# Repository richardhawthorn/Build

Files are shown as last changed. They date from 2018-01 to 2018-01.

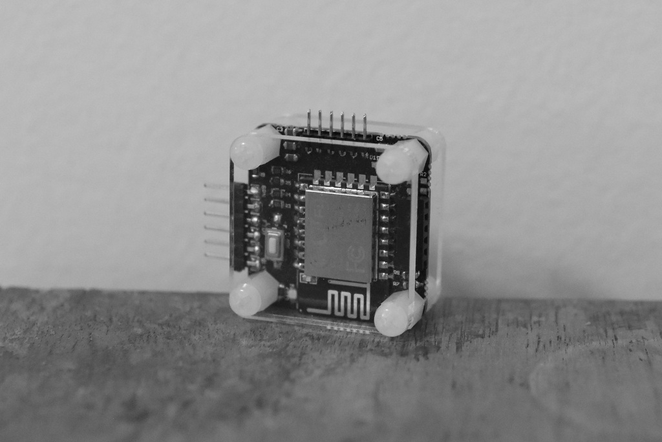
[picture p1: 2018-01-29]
Boards/Wifi Base/images/DSC_7675.JPG

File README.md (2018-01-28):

### Description

'Build' is an interchangeable set of input/output boards that let you create a complex system of sensors, buttons, actuators, transmitters and screens. Build starts with a wifi base and adds 13 different individually addressed i/o boards.  All boards clip together using a standard 6 pin header, so expanding the system quick and easy. 

This work is licensed under a Creative Commons Attribution-ShareAlike 4.0 International License.

<br />
Designed by <a xmlns:cc="http://creativecommons.org/ns#" href="http://www.richardhawthorn.com" property="cc:attributionName" rel="cc:attributionURL" target="_blank">Richard Hawthorn</a><br />
<a rel="license" href="http://creativecommons.org/licenses/by-sa/4.0/" target="_blank">View License</a>

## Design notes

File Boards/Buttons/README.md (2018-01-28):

### Description

Capacative button board for use in build system

### Features

- 4 capacative buttons on front plate
- QT1070 capacative chip
- ATtiny44 processor
- DIL switch for 8 board addresses
- i2c communication with base
- 3.3v operation
- Surface mount

### License

This work is licensed under a Creative Commons Attribution-ShareAlike 4.0 International License.

<br />
Designed by <a xmlns:cc="http://creativecommons.org/ns#" href="http://www.richardhawthorn.com" property="cc:attributionName" rel="cc:attributionURL" target="_blank">Richard Hawthorn</a><br />
<a rel="license" href="http://creativecommons.org/licenses/by-sa/4.0/" target="_blank">View License</a>

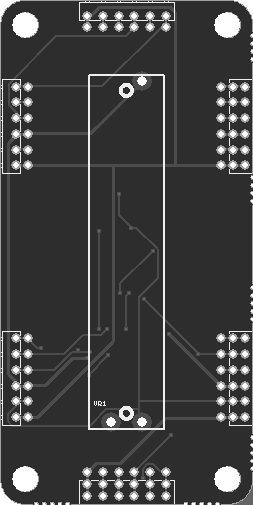
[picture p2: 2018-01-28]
Boards/Slider/images/pcb_front.png

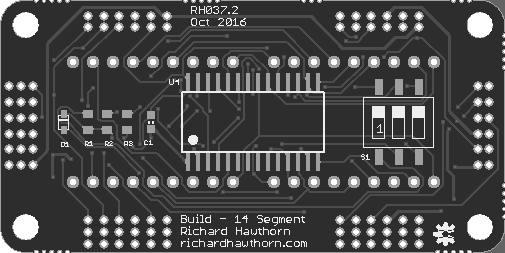
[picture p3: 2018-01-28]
Boards/14 Segment/images/pcb_back.png

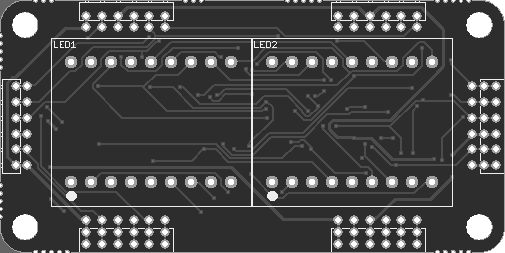
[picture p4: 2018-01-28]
Boards/14 Segment/images/pcb_front.png

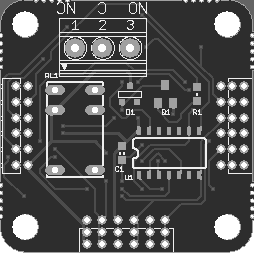
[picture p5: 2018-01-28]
Boards/Relay/images/pcb_front.png

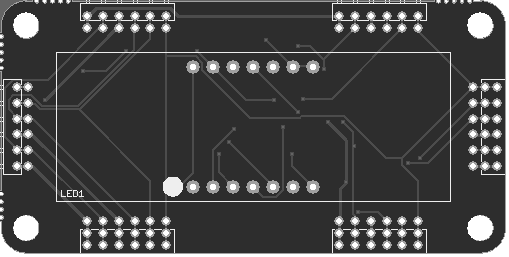
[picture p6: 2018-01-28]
Boards/7 Segment/images/pcb_front.png

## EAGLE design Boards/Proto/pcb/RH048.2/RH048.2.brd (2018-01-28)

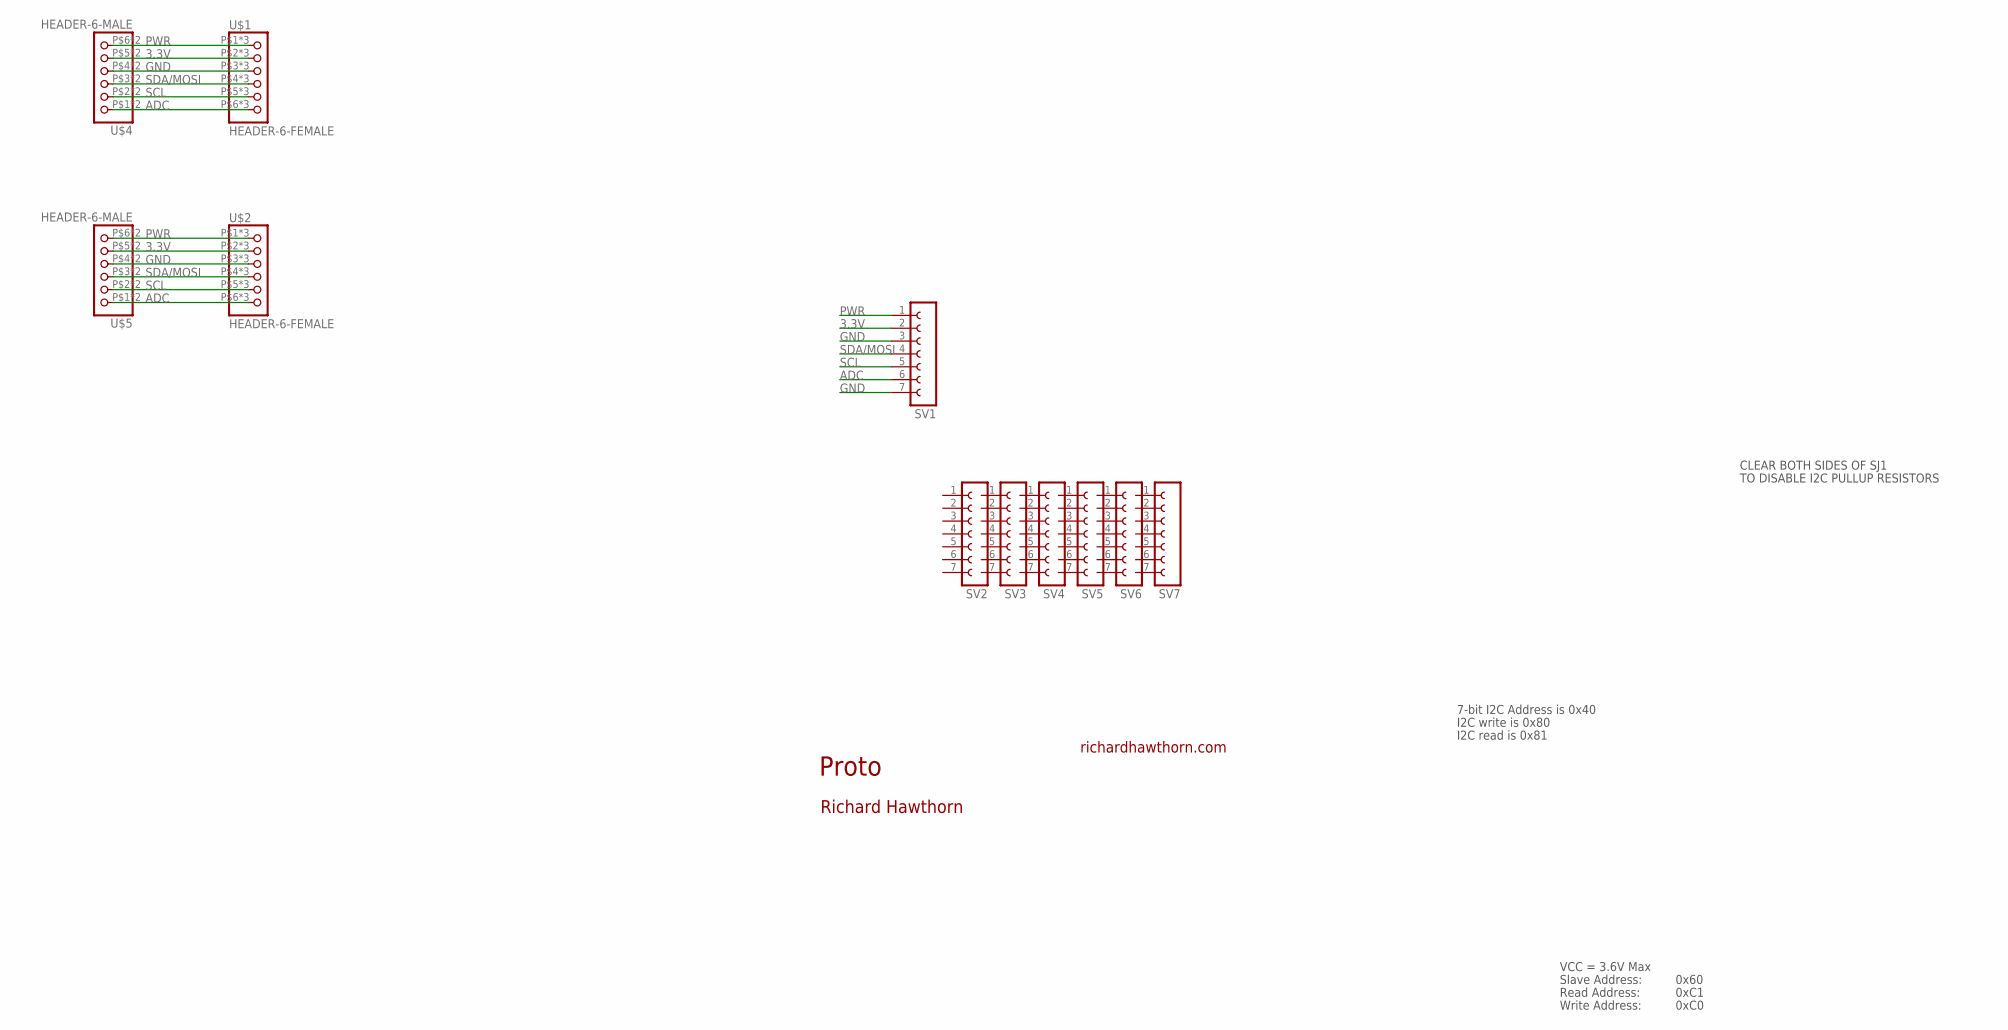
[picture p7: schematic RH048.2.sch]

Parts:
SV1, SV2, SV3, SV4, SV5, SV6, SV7: FE07-1; FE07
U$1, U$2: HEADER-6-FEMALE; 2MMHEADER6
U$4, U$5: HEADER-6-MALE; 2MMHEADERPIN6

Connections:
3.3V: SV1.2, U$1.P$2 (2), U$1.P$10 (2), U$1.P$18 (2), U$2.P$2 (2), U$2.P$10 (2), U$2.P$18 (2), U$4.P$5 (5), U$4.P$13 (5), U$5.P$5 (5), U$5.P$13 (5)
ADC: SV1.6, U$1.P$6 (6), U$1.P$14 (6), U$1.P$22 (6), U$2.P$6 (6), U$2.P$14 (6), U$2.P$22 (6), U$4.P$1 (1), U$4.P$9 (1), U$5.P$1 (1), U$5.P$9 (1)
GND: SV1.3, SV1.7, U$1.P$3 (3), U$1.P$11 (3), U$1.P$19 (3), U$2.P$3 (3), U$2.P$11 (3), U$2.P$19 (3), U$4.P$4 (4), U$4.P$12 (4), U$5.P$4 (4), U$5.P$12 (4)
PWR: SV1.1, U$1.P$1 (1), U$1.P$9 (1), U$1.P$17 (1), U$2.P$1 (1), U$2.P$9 (1), U$2.P$17 (1), U$4.P$6 (6), U$4.P$14 (6), U$5.P$6 (6), U$5.P$14 (6)
SCL: SV1.5, U$1.P$5 (5), U$1.P$13 (5), U$1.P$21 (5), U$2.P$5 (5), U$2.P$13 (5), U$2.P$21 (5), U$4.P$2 (2), U$4.P$10 (2), U$5.P$2 (2), U$5.P$10 (2)
SDA/MOSI: SV1.4, U$1.P$4 (4), U$1.P$12 (4), U$1.P$20 (4), U$2.P$4 (4), U$2.P$12 (4), U$2.P$20 (4), U$4.P$3 (3), U$4.P$11 (3), U$5.P$3 (3), U$5.P$11 (3)

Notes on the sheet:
Proto
richardhawthorn.com
Richard Hawthorn
CLEAR BOTH SIDES OF SJ1
TO DISABLE I2C PULLUP RESISTORS
7-bit I2C Address is 0x40
I2C write is 0x80
I2C read is 0x81
VCC = 3.6V Max
Read Address:
Write Address:
Slave Address:
0x60
0xC1
0xC0

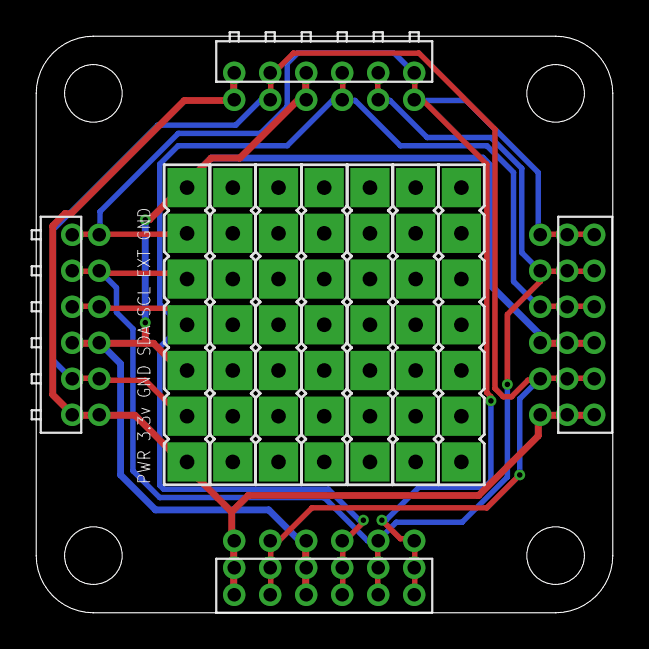
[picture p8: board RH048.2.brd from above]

Board: 2 copper layers, 32.0 x 32.0 mm, 12 parts (1 on the bottom side), 6 nets.

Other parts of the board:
U$3: OSHW-LOGO-S

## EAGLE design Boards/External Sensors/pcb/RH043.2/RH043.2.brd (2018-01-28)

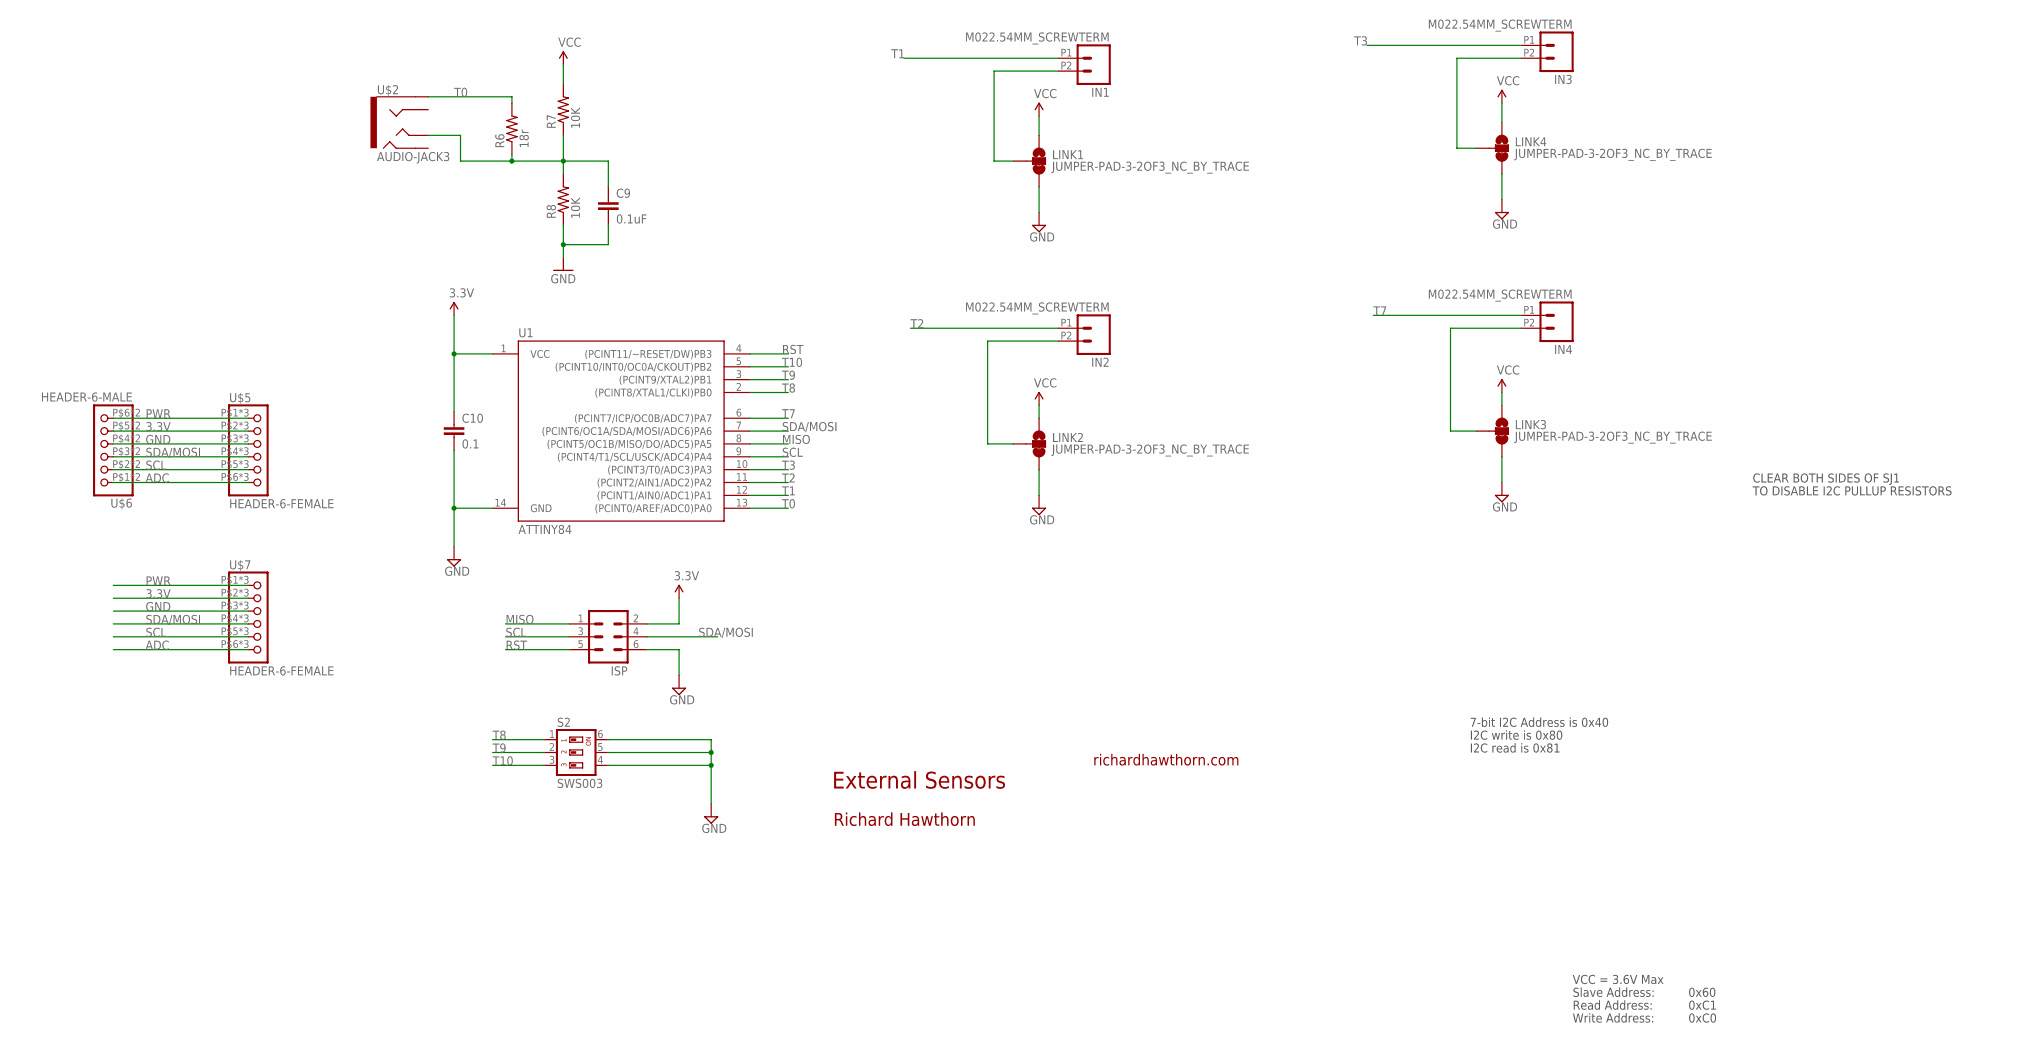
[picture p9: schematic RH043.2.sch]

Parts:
C9: 0.1uF; 0603-CAP
C10: 0.1; 0603-CAP
IN1, IN2, IN3, IN4: M022.54MM_SCREWTERM; 1X02_2.54_SCREWTERM
ISP: MA03-2
LINK1, LINK2, LINK3, LINK4: JUMPER-PAD-3-2OF3_NC_BY_TRACE; PAD-JUMPER-3-2OF3_NC_BY_TRACE_YES_SILK_FULL_BOX
R6: 18r; 0603-RES
R7, R8: 10K; 0603-RES
S2: SWS003; SMS-003
U1: ATTINY84; SO14
U$2: AUDIO-JACK3; AUDIO-JACK-TRRS-SMD
U$5, U$7: HEADER-6-FEMALE; 2MMHEADER6
U$6: HEADER-6-MALE; 2MMHEADERPIN6

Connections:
3.3V: C10.1, ISP.2, LINK1.1, LINK2.1, LINK3.1, LINK4.1, R7.2, U1.1 (VCC), U$5.P$2 (2), U$5.P$10 (2), U$5.P$18 (2), U$6.P$5 (5), U$6.P$13 (5), U$7.P$2 (2), U$7.P$10 (2), U$7.P$18 (2)
ADC: U$5.P$6 (6), U$5.P$14 (6), U$5.P$22 (6), U$6.P$1 (1), U$6.P$9 (1), U$7.P$6 (6), U$7.P$14 (6), U$7.P$22 (6)
GND: C9.2, C10.2, ISP.6, LINK1.3, LINK2.3, LINK3.3, LINK4.3, R8.1, S2.4, S2.5, S2.6, U1.14 (GND), U$5.P$3 (3), U$5.P$11 (3), U$5.P$19 (3), U$6.P$4 (4), U$6.P$12 (4), U$7.P$3 (3), U$7.P$11 (3), U$7.P$19 (3)
MISO: ISP.1, U1.8 ((PCINT5/OC1B/MISO/DO/ADC5)PA5)
unnamed: IN3.P2 (2), LINK4.2
unnamed: IN4.P2 (2), LINK3.2
unnamed: IN1.P2 (2), LINK1.2
unnamed: IN2.P2 (2), LINK2.2
PWR: U$5.P$1 (1), U$5.P$9 (1), U$5.P$17 (1), U$6.P$6 (6), U$6.P$14 (6), U$7.P$1 (1), U$7.P$9 (1), U$7.P$17 (1)
R6: C9.1, R6.1, R7.1, R8.2, U$2.TIP
RST: ISP.5, U1.4 ((PCINT11/~RESET/DW)PB3)
SCL: ISP.3, U1.9 ((PCINT4/T1/SCL/USCK/ADC4)PA4), U$5.P$5 (5), U$5.P$13 (5), U$5.P$21 (5), U$6.P$2 (2), U$6.P$10 (2), U$7.P$5 (5), U$7.P$13 (5), U$7.P$21 (5)
SDA/MOSI: ISP.4, U1.7 ((PCINT6/OC1A/SDA/MOSI/ADC6)PA6), U$5.P$4 (4), U$5.P$12 (4), U$5.P$20 (4), U$6.P$3 (3), U$6.P$11 (3), U$7.P$4 (4), U$7.P$12 (4), U$7.P$20 (4)
T0: R6.2, U1.13 ((PCINT0/AREF/ADC0)PA0), U$2.EARTH
T1: IN1.P1 (1), U1.12 ((PCINT1/AIN0/ADC1)PA1)
T2: IN2.P1 (1), U1.11 ((PCINT2/AIN1/ADC2)PA2)
T3: IN3.P1 (1), U1.10 ((PCINT3/T0/ADC3)PA3)
T7: IN4.P1 (1), U1.6 ((PCINT7/ICP/OC0B/ADC7)PA7)
T8: S2.1, U1.2 ((PCINT8/XTAL1/CLKI)PB0)
T9: S2.2, U1.3 ((PCINT9/XTAL2)PB1)
T10: S2.3, U1.5 ((PCINT10/INT0/OC0A/CKOUT)PB2)

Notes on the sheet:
External Sensors
richardhawthorn.com
Richard Hawthorn
CLEAR BOTH SIDES OF SJ1
TO DISABLE I2C PULLUP RESISTORS
7-bit I2C Address is 0x40
I2C write is 0x80
I2C read is 0x81
VCC = 3.6V Max
Read Address:
Write Address:
Slave Address:
0x60
0xC1
0xC0

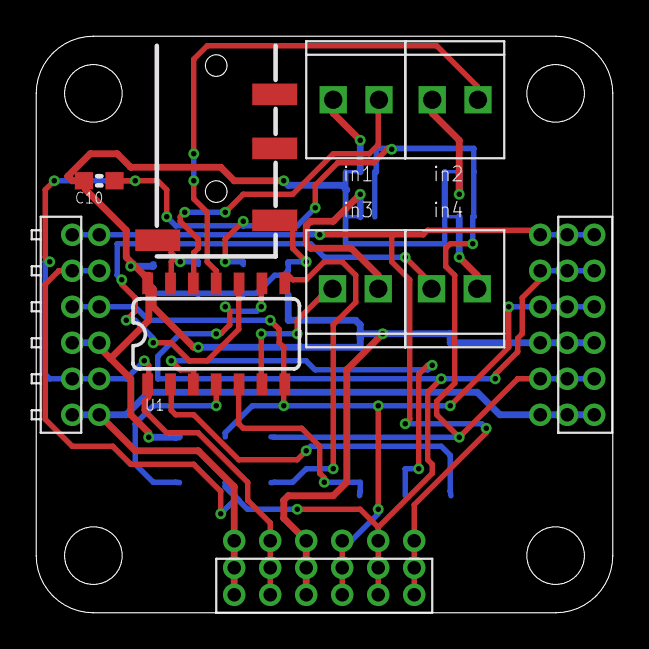
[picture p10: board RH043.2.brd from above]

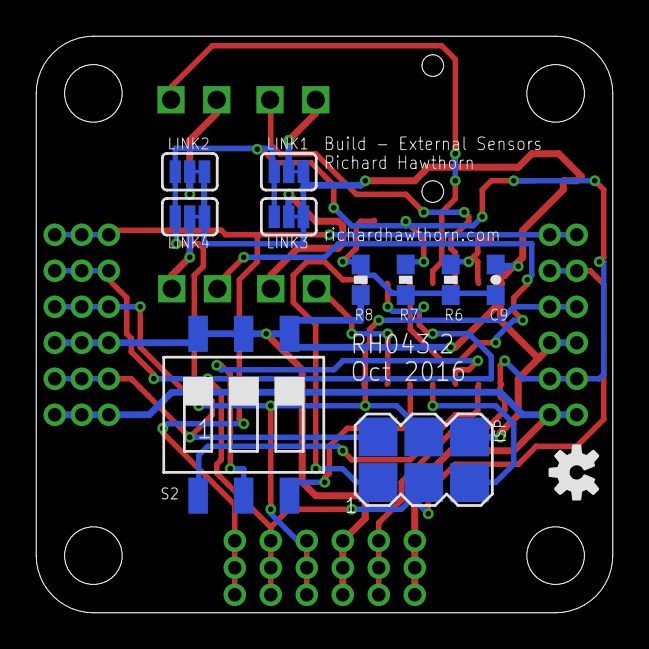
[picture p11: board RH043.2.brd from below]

Board: 2 copper layers, 32.0 x 32.0 mm, 21 parts (11 on the bottom side), 21 nets.

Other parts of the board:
U$3: OSHW-LOGO-S

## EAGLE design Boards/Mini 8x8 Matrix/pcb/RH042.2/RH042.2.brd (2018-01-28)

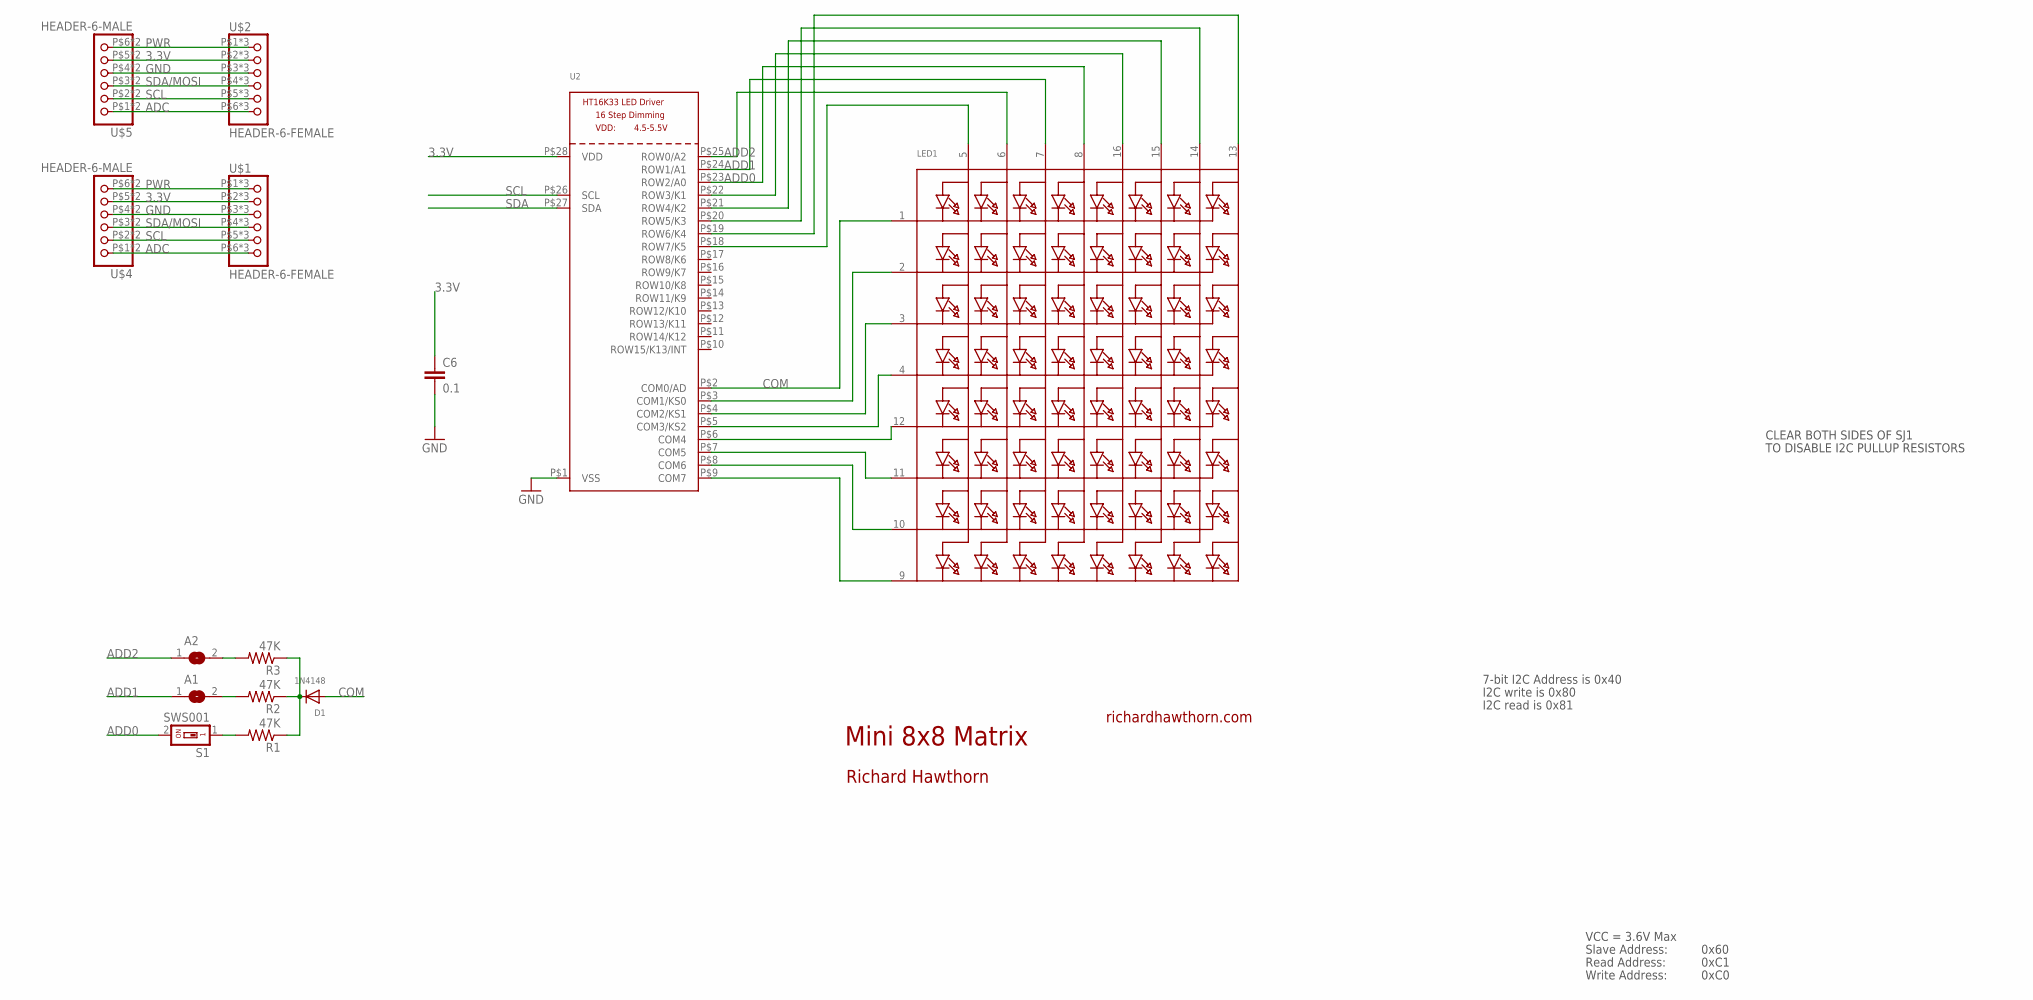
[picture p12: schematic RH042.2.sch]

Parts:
A1, A2: SJ
C6: 0.1; 0603-CAP
D1: 1N4148; SOD-323F
LED1: SEGMENT_8X8_ROWCATHODE; SEGMENT_BL-M07C881UR
R1, R2, R3: 47K; R0805
S1: SWS001; SMS-001
U2: HT16K33_SOP28; SOP28_300MIL
U$1, U$2: HEADER-6-FEMALE; 2MMHEADER6
U$4, U$5: HEADER-6-MALE; 2MMHEADERPIN6

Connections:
3.3V: C6.1, U2.P$28 (VDD), U$1.P$2 (2), U$1.P$10 (2), U$1.P$18 (2), U$2.P$2 (2), U$2.P$10 (2), U$2.P$18 (2), U$4.P$5 (5), U$4.P$13 (5), U$5.P$5 (5), U$5.P$13 (5)
ADC: U$1.P$6 (6), U$1.P$14 (6), U$1.P$22 (6), U$2.P$6 (6), U$2.P$14 (6), U$2.P$22 (6), U$4.P$1 (1), U$4.P$9 (1), U$5.P$1 (1), U$5.P$9 (1)
ADD0: LED1.8 (A4), S1.2, U2.P$23 (ROW2/A0)
ADD1: A1.1, LED1.7 (A3), U2.P$24 (ROW1/A1)
ADD2: A2.1, LED1.6 (A2), U2.P$25 (ROW0/A2)
COM: D1.A, LED1.1 (K1), U2.P$2 (COM0/AD)
GND: C6.2, U2.P$1 (VSS), U$1.P$3 (3), U$1.P$11 (3), U$1.P$19 (3), U$2.P$3 (3), U$2.P$11 (3), U$2.P$19 (3), U$4.P$4 (4), U$4.P$12 (4), U$5.P$4 (4), U$5.P$12 (4)
unnamed: LED1.9 (K8), U2.P$9 (COM7)
unnamed: A2.2, R3.2
unnamed: LED1.10 (K7), U2.P$8 (COM6)
unnamed: LED1.11 (K6), U2.P$7 (COM5)
unnamed: D1.C, R1.1, R2.1, R3.1
unnamed: R1.2, S1.1
unnamed: A1.2, R2.2
unnamed: LED1.12 (K5), U2.P$6 (COM4)
unnamed: LED1.4 (K4), U2.P$5 (COM3/KS2)
unnamed: LED1.3 (K3), U2.P$4 (COM2/KS1)
unnamed: LED1.2 (K2), U2.P$3 (COM1/KS0)
unnamed: LED1.16 (A5), U2.P$22 (ROW3/K1)
unnamed: LED1.15 (A6), U2.P$21 (ROW4/K2)
unnamed: LED1.5 (A1), U2.P$18 (ROW7/K5)
PWR: U$1.P$1 (1), U$1.P$9 (1), U$1.P$17 (1), U$2.P$1 (1), U$2.P$9 (1), U$2.P$17 (1), U$4.P$6 (6), U$4.P$14 (6), U$5.P$6 (6), U$5.P$14 (6)
SCL: U2.P$26 (SCL), U$1.P$5 (5), U$1.P$13 (5), U$1.P$21 (5), U$2.P$5 (5), U$2.P$13 (5), U$2.P$21 (5), U$4.P$2 (2), U$4.P$10 (2), U$5.P$2 (2), U$5.P$10 (2)
SDA: U2.P$27 (SDA)
SDA/MOSI: U$1.P$4 (4), U$1.P$12 (4), U$1.P$20 (4), U$2.P$4 (4), U$2.P$12 (4), U$2.P$20 (4), U$4.P$3 (3), U$4.P$11 (3), U$5.P$3 (3), U$5.P$11 (3)
SEG_F: LED1.14 (A7), U2.P$20 (ROW5/K3)
SEG_G: LED1.13 (A8), U2.P$19 (ROW6/K4)

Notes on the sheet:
Mini 8x8 Matrix
richardhawthorn.com
Richard Hawthorn
CLEAR BOTH SIDES OF SJ1
TO DISABLE I2C PULLUP RESISTORS
7-bit I2C Address is 0x40
I2C write is 0x80
I2C read is 0x81
VCC = 3.6V Max
Read Address:
Write Address:
Slave Address:
0x60
0xC1
0xC0

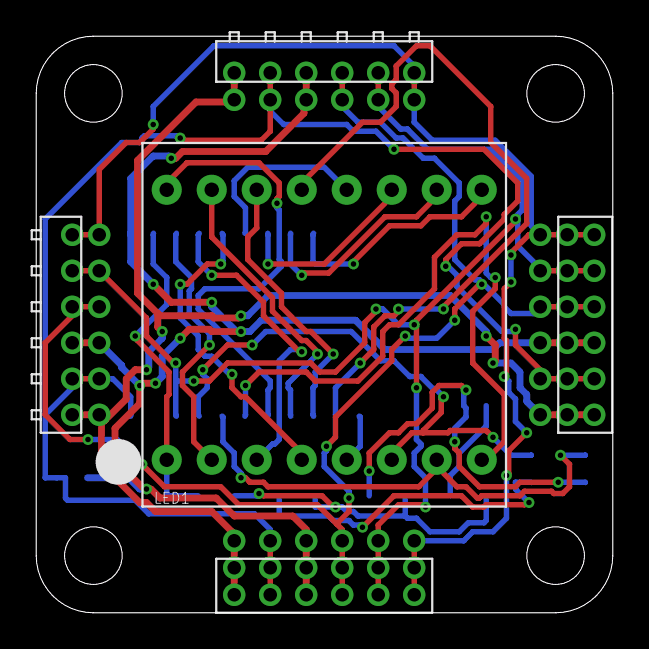
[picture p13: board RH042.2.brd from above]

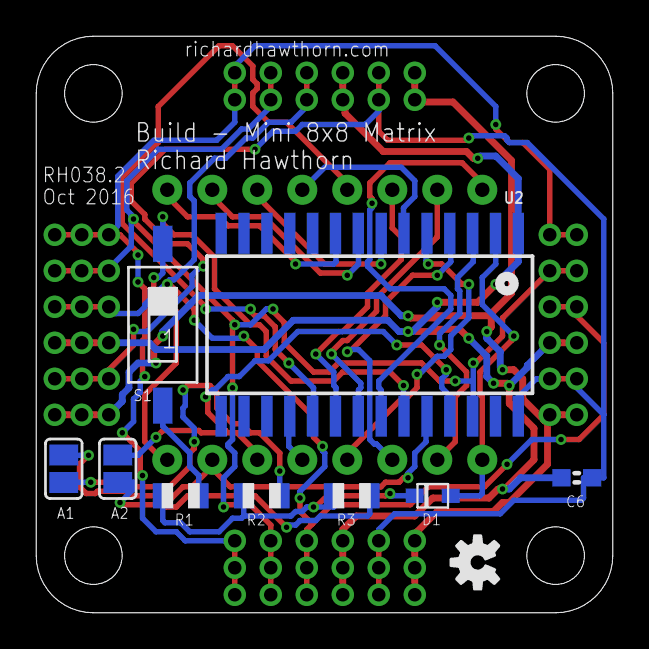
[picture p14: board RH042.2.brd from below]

Board: 2 copper layers, 32.0 x 32.0 mm, 15 parts (10 on the bottom side), 26 nets.

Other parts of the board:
U$3: OSHW-LOGO-S

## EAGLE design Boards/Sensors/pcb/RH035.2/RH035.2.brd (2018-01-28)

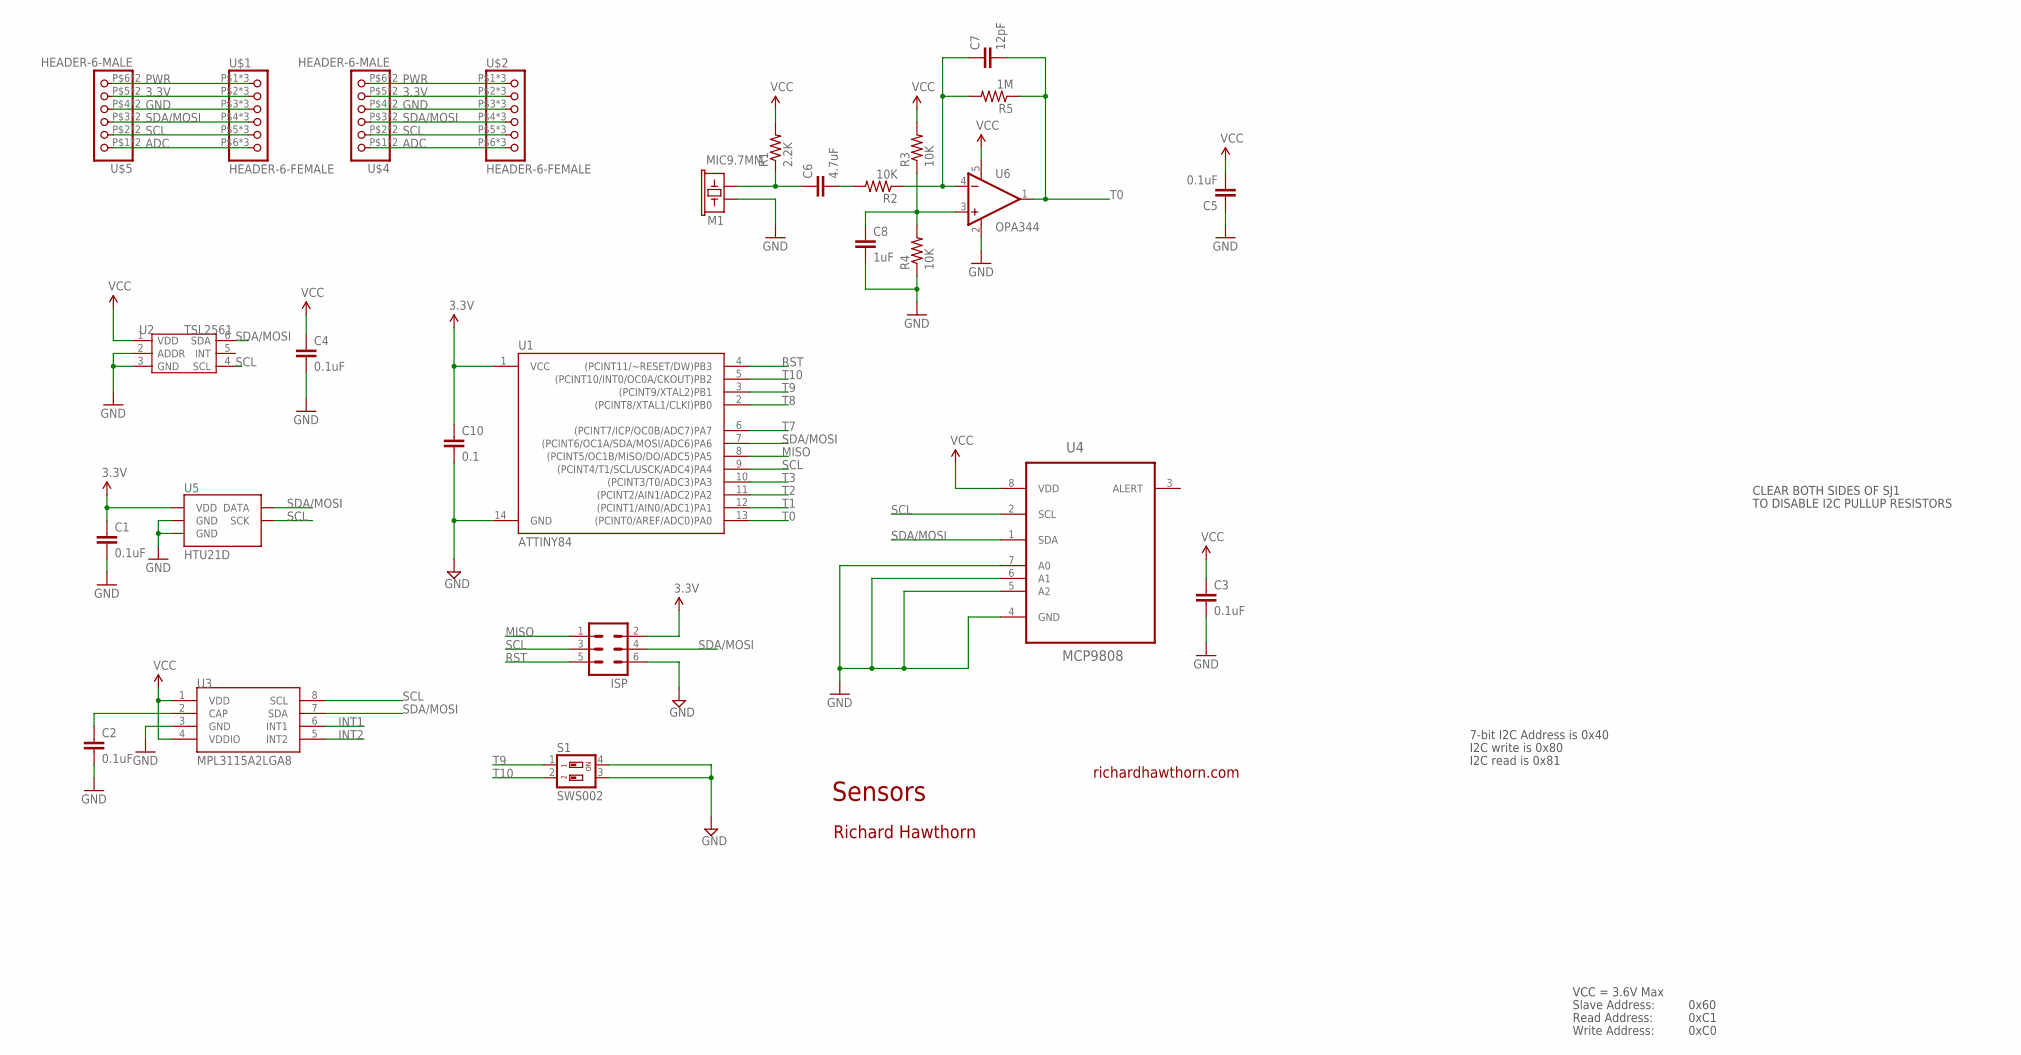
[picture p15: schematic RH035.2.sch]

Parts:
C1, C2, C5: 0.1uF; 0805
C3, C4: 0.1uF; 0603-CAP
C6: 4.7uF; 0805
C7: 12pF; 0805
C8: 1uF; 0805
C10: 0.1; 0603-CAP
ISP: MA03-2
M1: MIC9.7MM; MIC-9.7MM
R1: 2.2K; 0805
R2, R3, R4: 10K; 0805
R5: 1M; 0805
S1: SWS002; SMS-002
U1: ATTINY84; SO14
U2: TSL2561; TMB-6
U3: MPL3115A2LGA8; LGA8
U4: MCP9808; SOP65P490X110-8N
U5: HTU21D
U6: OPA344; SOT23-5
U$1, U$2: HEADER-6-FEMALE; 2MMHEADER6
U$4, U$5: HEADER-6-MALE; 2MMHEADERPIN6

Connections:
3.3V: C1.1, C3.1, C4.1, C5.2, C10.1, ISP.2, R1.2, R3.2, U1.1 (VCC), U2.1 (VDD), U3.1 (VDD), U3.4 (VDDIO), U4.8 (VDD), U5.VDD, U6.5 (V+), U$1.P$2 (2), U$1.P$10 (2), U$1.P$18 (2), U$2.P$2 (2), U$2.P$10 (2), U$2.P$18 (2), U$4.P$5 (5), U$4.P$13 (5), U$5.P$5 (5), U$5.P$13 (5)
ADC: U$1.P$6 (6), U$1.P$14 (6), U$1.P$22 (6), U$2.P$6 (6), U$2.P$14 (6), U$2.P$22 (6), U$4.P$1 (1), U$4.P$9 (1), U$5.P$1 (1), U$5.P$9 (1)
GND: C1.2, C2.2, C3.2, C4.2, C5.1, C8.2, C10.2, ISP.6, M1.2, R4.1, S1.3, S1.4, U1.14 (GND), U2.2 (ADDR), U2.3 (GND), U3.3 (GND), U4.4 (GND), U4.5 (A2), U4.6 (A1), U4.7 (A0), U5.7 (GND), U5.GND, U6.2 (V-), U$1.P$3 (3), U$1.P$11 (3), U$1.P$19 (3), U$2.P$3 (3), U$2.P$11 (3), U$2.P$19 (3), U$4.P$4 (4), U$4.P$12 (4), U$5.P$4 (4), U$5.P$12 (4)
INT1: U3.6 (INT1)
INT2: U3.5 (INT2)
MISO: ISP.1, U1.8 ((PCINT5/OC1B/MISO/DO/ADC5)PA5)
unnamed: C6.1, M1.1, R1.1
unnamed: C7.1, R2.1, R5.2, U6.4 (-IN)
unnamed: C6.2, R2.2
unnamed: C8.1, R3.1, R4.2, U6.3 (+IN)
unnamed: C2.1, U3.2 (CAP)
PWR: U$1.P$1 (1), U$1.P$9 (1), U$1.P$17 (1), U$2.P$1 (1), U$2.P$9 (1), U$2.P$17 (1), U$4.P$6 (6), U$4.P$14 (6), U$5.P$6 (6), U$5.P$14 (6)
RST: ISP.5, U1.4 ((PCINT11/~RESET/DW)PB3)
SCL: ISP.3, U1.9 ((PCINT4/T1/SCL/USCK/ADC4)PA4), U2.4 (SCL), U3.8 (SCL), U4.2 (SCL), U5.SCK, U$1.P$5 (5), U$1.P$13 (5), U$1.P$21 (5), U$2.P$5 (5), U$2.P$13 (5), U$2.P$21 (5), U$4.P$2 (2), U$4.P$10 (2), U$5.P$2 (2), U$5.P$10 (2)
SDA/MOSI: ISP.4, U1.7 ((PCINT6/OC1A/SDA/MOSI/ADC6)PA6), U2.6 (SDA), U3.7 (SDA), U4.1 (SDA), U5.DATA, U$1.P$4 (4), U$1.P$12 (4), U$1.P$20 (4), U$2.P$4 (4), U$2.P$12 (4), U$2.P$20 (4), U$4.P$3 (3), U$4.P$11 (3), U$5.P$3 (3), U$5.P$11 (3)
T0: C7.2, R5.1, U1.13 ((PCINT0/AREF/ADC0)PA0), U6.1 (OUT)
T1: U1.12 ((PCINT1/AIN0/ADC1)PA1)
T2: U1.11 ((PCINT2/AIN1/ADC2)PA2)
T3: U1.10 ((PCINT3/T0/ADC3)PA3)
T7: U1.6 ((PCINT7/ICP/OC0B/ADC7)PA7)
T8: U1.2 ((PCINT8/XTAL1/CLKI)PB0)
T9: S1.1, U1.3 ((PCINT9/XTAL2)PB1)
T10: S1.2, U1.5 ((PCINT10/INT0/OC0A/CKOUT)PB2)

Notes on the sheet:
Sensors
richardhawthorn.com
Richard Hawthorn
CLEAR BOTH SIDES OF SJ1
TO DISABLE I2C PULLUP RESISTORS
7-bit I2C Address is 0x40
I2C write is 0x80
I2C read is 0x81
VCC = 3.6V Max
Read Address:
Write Address:
Slave Address:
0x60
0xC1
0xC0

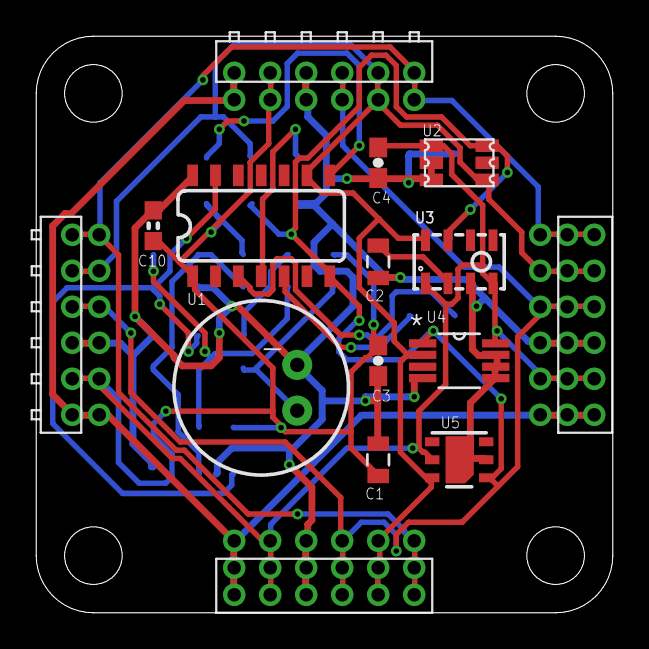
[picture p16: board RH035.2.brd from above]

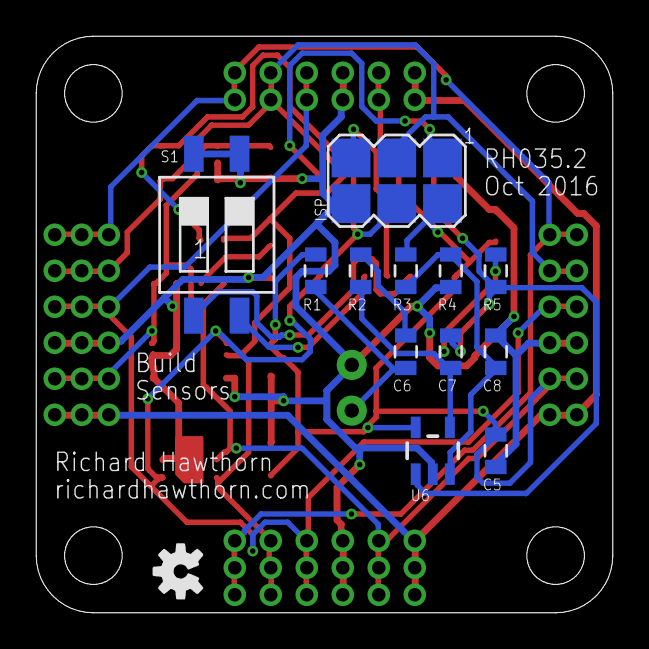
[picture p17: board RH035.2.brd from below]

Board: 2 copper layers, 32.0 x 32.0 mm, 28 parts (13 on the bottom side), 16 nets.

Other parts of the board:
U$3: OSHW-LOGO-S

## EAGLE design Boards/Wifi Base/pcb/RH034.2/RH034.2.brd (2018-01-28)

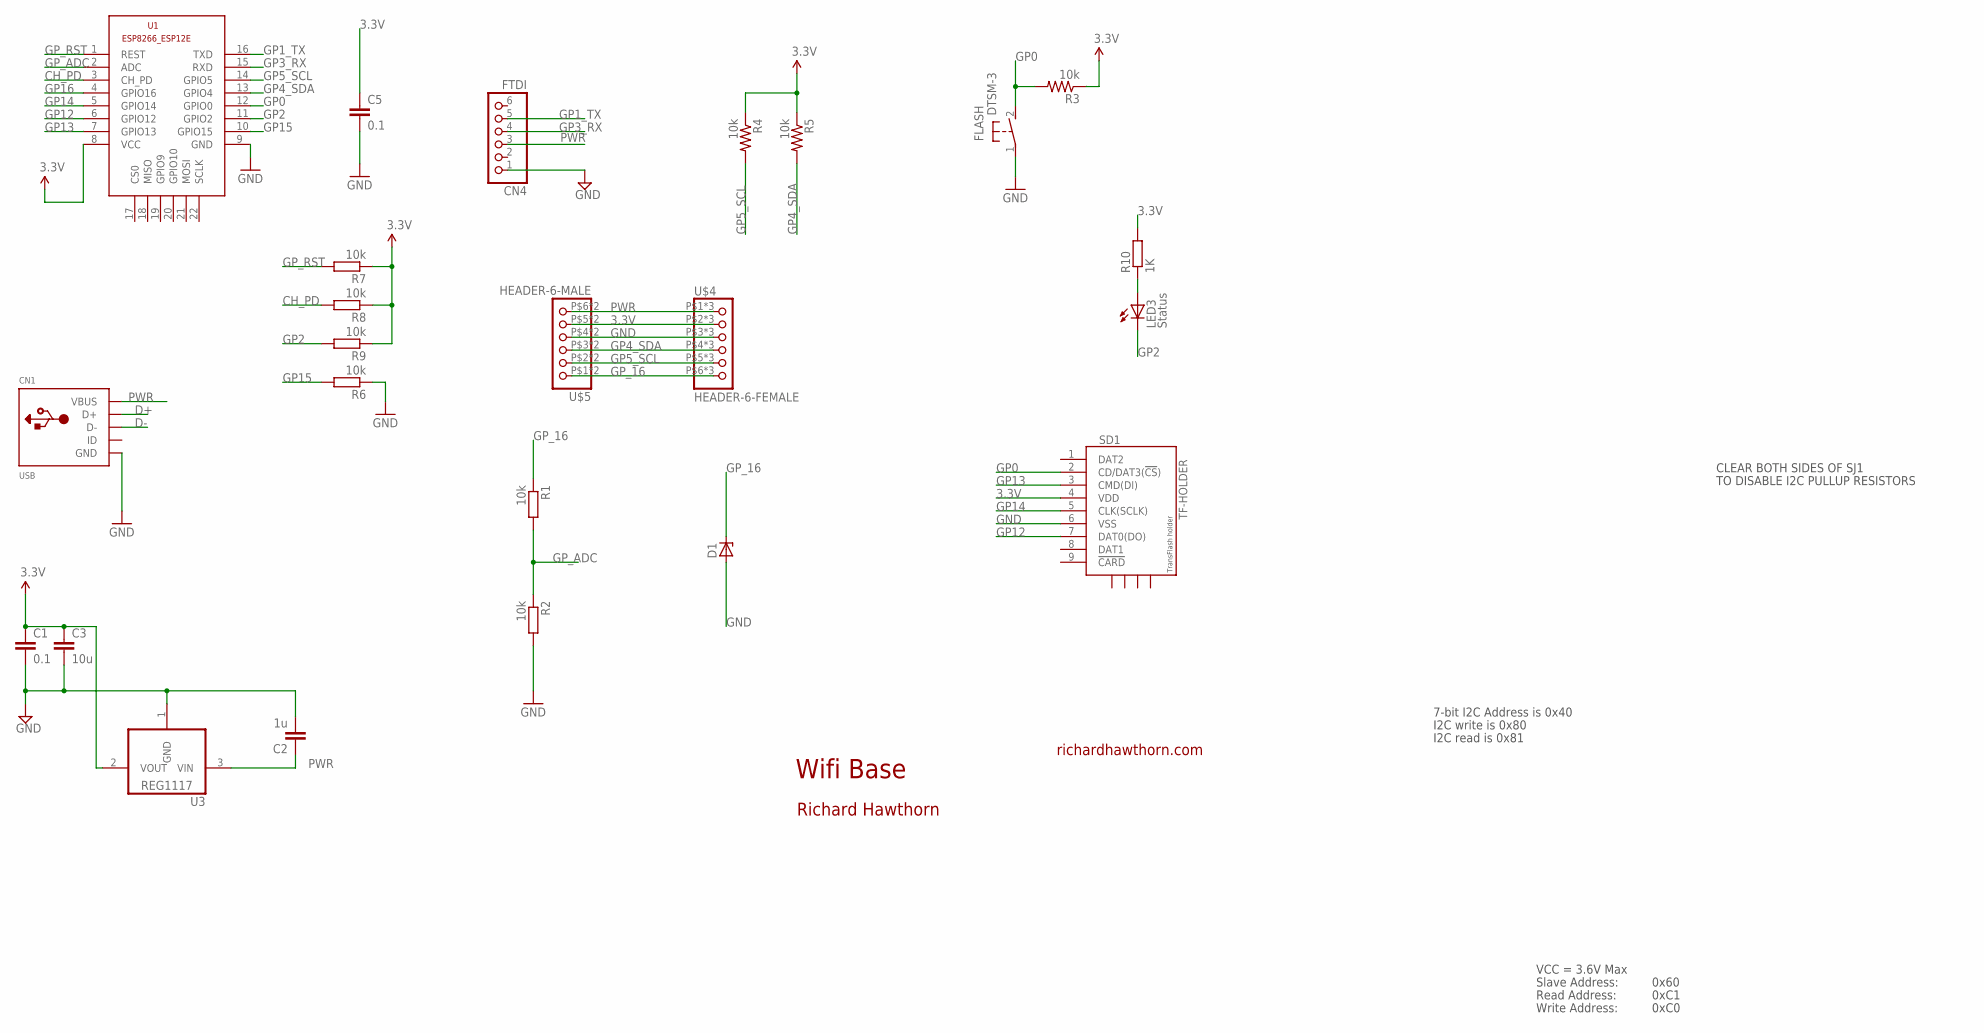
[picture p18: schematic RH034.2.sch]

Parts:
C1, C5: 0.1; 0603-CAP
C2: 1u; 0603-CAP
C3: 10u; 0805-CAP
CN1: USB; USB-MINIB
CN4: FTDI; 1X06
D1: ZENER-DIODESOT23; SOT23
FLASH: DTSM-3
LED3: Status; CHIPLED_0805
R1, R2, R6, R7, R8, R9: 10k; R0603
R3, R4, R5: 10k; 0805
R10: 1K; R0603
SD1: TF-HOLDER; TF-PULL
U1: ESP8266-12EESP8266-ESP12E; ESP8266-ESP12E
U3: REG1117; SOT223
U$4: HEADER-6-FEMALE; 2MMHEADER6
U$5: HEADER-6-MALE; 2MMHEADERPIN6

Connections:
3.3V: C1.1, C3.1, C5.1, R3.1, R4.1, R5.1, R7.1, R8.1, R9.1, R10.2, SD1.4 (VDD), U1.8 (VCC), U3.2 (VOUT), U$4.P$2 (2), U$4.P$10 (2), U$4.P$18 (2), U$5.P$5 (5), U$5.P$13 (5)
CH_PD: R8.2, U1.3 (CH_PD)
D+: CN1.D+
D-: CN1.D-
GND: C1.2, C2.2, C3.2, C5.2, CN1.GND, CN4.1, D1.1 (A), FLASH.1, R2.2, R6.1, SD1.6 (VSS), U1.9 (GND), U3.1 (GND), U$4.P$3 (3), U$4.P$11 (3), U$4.P$19 (3), U$5.P$4 (4), U$5.P$12 (4)
GP0: FLASH.2, R3.2, SD1.2 (CD/DAT3(!CS!)), U1.12 (GPIO0)
GP1_TX: CN4.5, U1.16 (TXD)
GP2: LED3.C, R9.2, U1.11 (GPIO2)
GP3_RX: CN4.4, U1.15 (RXD)
GP4_SDA: R5.2, U1.13 (GPIO4), U$4.P$4 (4), U$4.P$12 (4), U$4.P$20 (4), U$5.P$3 (3), U$5.P$11 (3)
GP5_SCL: R4.2, U1.14 (GPIO5), U$4.P$5 (5), U$4.P$13 (5), U$4.P$21 (5), U$5.P$2 (2), U$5.P$10 (2)
GP12: SD1.7 (DAT0(DO)), U1.6 (GPIO12)
GP13: SD1.3 (CMD(DI)), U1.7 (GPIO13)
GP14: SD1.5 (CLK(SCLK)), U1.5 (GPIO14)
GP15: R6.2, U1.10 (GPIO15)
GP16: U1.4 (GPIO16)
GP_16: D1.3 (C), R1.1, U$4.P$6 (6), U$4.P$14 (6), U$4.P$22 (6), U$5.P$1 (1), U$5.P$9 (1)
GP_ADC: R1.2, R2.1, U1.2 (ADC)
GP_RST: R7.2, U1.1 (REST)
unnamed: LED3.A, R10.1
PWR: C2.1, CN1.VBUS, CN4.3, U3.3 (VIN), U$4.P$1 (1), U$4.P$9 (1), U$4.P$17 (1), U$5.P$6 (6), U$5.P$14 (6)

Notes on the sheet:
Wifi Base
richardhawthorn.com
Richard Hawthorn
CLEAR BOTH SIDES OF SJ1
TO DISABLE I2C PULLUP RESISTORS
7-bit I2C Address is 0x40
I2C write is 0x80
I2C read is 0x81
VCC = 3.6V Max
Read Address:
Write Address:
Slave Address:
0x60
0xC1
0xC0



Board: 2 copper layers, 32.0 x 32.0 mm, 25 parts (4 on the bottom side), 18 nets.

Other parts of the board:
U$3: OSHW-LOGO-S

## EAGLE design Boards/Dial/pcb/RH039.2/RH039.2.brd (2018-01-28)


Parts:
C1: 0.1; 0603-CAP
ISP: MA03-2
R1: 10k; 0402-RES
R2, R3: 180; 0402-RES
R4: 300; 0402-RES
S2: SWS002; SMS-002
U1: ATTINY84; SO14
U4: ENCODER_RGB; ENCODER_LED_RGB
U$1, U$2: HEADER-6-FEMALE; 2MMHEADER6
U$4, U$5: HEADER-6-MALE; 2MMHEADERPIN6

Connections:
3.3V: C1.1, ISP.2, U1.1 (VCC), U4.VCC, U$1.P$2 (2), U$1.P$10 (2), U$1.P$18 (2), U$2.P$2 (2), U$2.P$10 (2), U$2.P$18 (2), U$4.P$5 (5), U$4.P$13 (5), U$5.P$5 (5), U$5.P$13 (5)
ADC: U$1.P$6 (6), U$1.P$14 (6), U$1.P$22 (6), U$2.P$6 (6), U$2.P$14 (6), U$2.P$22 (6), U$4.P$1 (1), U$4.P$9 (1), U$5.P$1 (1), U$5.P$9 (1)
GND: C1.2, ISP.6, R1.1, S2.3, S2.4, U1.14 (GND), U4.C, U$1.P$3 (3), U$1.P$11 (3), U$1.P$19 (3), U$2.P$3 (3), U$2.P$11 (3), U$2.P$19 (3), U$4.P$4 (4), U$4.P$12 (4), U$5.P$4 (4), U$5.P$12 (4)
LED-B: R2.1, U4.BL
LED-G: R3.1, U4.G
LED-R: R4.1, U4.R
MISO: ISP.1, U1.8 ((PCINT5/OC1B/MISO/DO/ADC5)PA5)
PWR: U$1.P$1 (1), U$1.P$9 (1), U$1.P$17 (1), U$2.P$1 (1), U$2.P$9 (1), U$2.P$17 (1), U$4.P$6 (6), U$4.P$14 (6), U$5.P$6 (6), U$5.P$14 (6)
RST: ISP.5, U1.4 ((PCINT11/~RESET/DW)PB3)
SCL: ISP.3, U1.9 ((PCINT4/T1/SCL/USCK/ADC4)PA4), U$1.P$5 (5), U$1.P$13 (5), U$1.P$21 (5), U$2.P$5 (5), U$2.P$13 (5), U$2.P$21 (5), U$4.P$2 (2), U$4.P$10 (2), U$5.P$2 (2), U$5.P$10 (2)
SDA/MOSI: ISP.4, U1.7 ((PCINT6/OC1A/SDA/MOSI/ADC6)PA6), U$1.P$4 (4), U$1.P$12 (4), U$1.P$20 (4), U$2.P$4 (4), U$2.P$12 (4), U$2.P$20 (4), U$4.P$3 (3), U$4.P$11 (3), U$5.P$3 (3), U$5.P$11 (3)
T0: U1.13 ((PCINT0/AREF/ADC0)PA0), U4.A
T1: U1.12 ((PCINT1/AIN0/ADC1)PA1), U4.B
T2: R1.2, U1.11 ((PCINT2/AIN1/ADC2)PA2), U4.SW
T3: R4.2, U1.10 ((PCINT3/T0/ADC3)PA3)
T7: R3.2, U1.6 ((PCINT7/ICP/OC0B/ADC7)PA7)
T8: R2.2, U1.2 ((PCINT8/XTAL1/CLKI)PB0)
T9: S2.1, U1.3 ((PCINT9/XTAL2)PB1)
T10: S2.2, U1.5 ((PCINT10/INT0/OC0A/CKOUT)PB2)

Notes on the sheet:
Dial
richardhawthorn.com
Richard Hawthorn
CLEAR BOTH SIDES OF SJ1
TO DISABLE I2C PULLUP RESISTORS
7-bit I2C Address is 0x40
I2C write is 0x80
I2C read is 0x81
VCC = 3.6V Max
Read Address:
Write Address:
Slave Address:
0x60
0xC1
0xC0



Board: 2 copper layers, 32.0 x 32.0 mm, 14 parts (9 on the bottom side), 19 nets.

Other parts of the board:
U$3: OSHW-LOGO-S

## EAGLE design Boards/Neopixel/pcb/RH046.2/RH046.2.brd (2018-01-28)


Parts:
C1, C2, C3, C4, C5: 0.1; 0603-CAP
C6: 100uF; EIA7343
ISP: MA03-2
L1, L2, L3, L4: WS2812B
R4: 100r; 0603-RES
S1: SWS003; SMS-003
SJ1, SJ2: SOLDERJUMPERNO; SJ_2S-NO
U1: ATTINY84; SO14
U$1, U$2: HEADER-6-FEMALE; 2MMHEADER6
U$4, U$5: HEADER-6-MALE; 2MMHEADERPIN6

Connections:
3.3V: C1.1, ISP.2, SJ1.1, U1.1 (VCC), U$1.P$2 (2), U$1.P$10 (2), U$1.P$18 (2), U$2.P$2 (2), U$2.P$10 (2), U$2.P$18 (2), U$4.P$5 (5), U$4.P$13 (5), U$5.P$5 (5), U$5.P$13 (5)
ADC: U$1.P$6 (6), U$1.P$14 (6), U$1.P$22 (6), U$2.P$6 (6), U$2.P$14 (6), U$2.P$22 (6), U$4.P$1 (1), U$4.P$9 (1), U$5.P$1 (1), U$5.P$9 (1)
GND: C1.2, ISP.6, S1.4, S1.5, S1.6, SJ2.1, U1.14 (GND), U$1.P$3 (3), U$1.P$11 (3), U$1.P$19 (3), U$2.P$3 (3), U$2.P$11 (3), U$2.P$19 (3), U$4.P$4 (4), U$4.P$12 (4), U$5.P$4 (4), U$5.P$12 (4)
LED-OUT-1: L1.2-DOUT (DOUT), L2.4-DIN (DIN)
LED-OUT-2: L3.2-DOUT (DOUT), L4.4-DIN (DIN)
LED-OUT-3: L4.2-DOUT (DOUT)
LED_DATA: L1.4-DIN (DIN), R4.2
LED_NEG: C2.2, C3.2, C4.2, C5.2, C6.C (-), L1.3-GND (GND), L2.3-GND (GND), L3.3-GND (GND), L4.3-GND (GND), SJ2.2
LED_POS: C2.1, C3.1, C4.1, C5.1, C6.A (+), L1.1-VDD (VDD), L2.1-VDD (VDD), L3.1-VDD (VDD), L4.1-VDD (VDD), SJ1.2
MISO: ISP.1, U1.8 ((PCINT5/OC1B/MISO/DO/ADC5)PA5)
unnamed: L2.2-DOUT (DOUT), L3.4-DIN (DIN)
PWR: U$1.P$1 (1), U$1.P$9 (1), U$1.P$17 (1), U$2.P$1 (1), U$2.P$9 (1), U$2.P$17 (1), U$4.P$6 (6), U$4.P$14 (6), U$5.P$6 (6), U$5.P$14 (6)
RST: ISP.5, U1.4 ((PCINT11/~RESET/DW)PB3)
SCL: ISP.3, U1.9 ((PCINT4/T1/SCL/USCK/ADC4)PA4), U$1.P$5 (5), U$1.P$13 (5), U$1.P$21 (5), U$2.P$5 (5), U$2.P$13 (5), U$2.P$21 (5), U$4.P$2 (2), U$4.P$10 (2), U$5.P$2 (2), U$5.P$10 (2)
SDA/MOSI: ISP.4, U1.7 ((PCINT6/OC1A/SDA/MOSI/ADC6)PA6), U$1.P$4 (4), U$1.P$12 (4), U$1.P$20 (4), U$2.P$4 (4), U$2.P$12 (4), U$2.P$20 (4), U$4.P$3 (3), U$4.P$11 (3), U$5.P$3 (3), U$5.P$11 (3)
T0: R4.1, U1.13 ((PCINT0/AREF/ADC0)PA0)
T1: U1.12 ((PCINT1/AIN0/ADC1)PA1)
T2: U1.11 ((PCINT2/AIN1/ADC2)PA2)
T3: U1.10 ((PCINT3/T0/ADC3)PA3)
T7: U1.6 ((PCINT7/ICP/OC0B/ADC7)PA7)
T8: S1.1, U1.2 ((PCINT8/XTAL1/CLKI)PB0)
T9: S1.2, U1.3 ((PCINT9/XTAL2)PB1)
T10: S1.3, U1.5 ((PCINT10/INT0/OC0A/CKOUT)PB2)

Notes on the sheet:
Neopixels
richardhawthorn.com
Richard Hawthorn
CLEAR BOTH SIDES OF SJ1
TO DISABLE I2C PULLUP RESISTORS
7-bit I2C Address is 0x40
I2C write is 0x80
I2C read is 0x81
VCC = 3.6V Max
Read Address:
Write Address:
Slave Address:
0x60
0xC1
0xC0



Board: 2 copper layers, 32.0 x 32.0 mm, 21 parts (9 on the bottom side), 18 nets.

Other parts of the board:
U$3: OSHW-LOGO-S

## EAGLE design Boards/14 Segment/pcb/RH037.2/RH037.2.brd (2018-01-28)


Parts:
C1: 0.1; 0603-CAP
D1: 1N4148; SOD-323F
LED1, LED2: DISP_SEGMENT_STARBURST_DUAL_COMMONCATHODE; SEGMENT_STARTBUST_DUAL_KWA-541CBB
R1, R2, R3: 47K; R0805
S1: SWS003; SMS-003
U4: HT16K33_SOP28; SOP28_300MIL
U$1, U$2, U$4: HEADER-6-FEMALE; 2MMHEADER6
U$5, U$6, U$7: HEADER-6-MALE; 2MMHEADERPIN6

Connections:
3.3V: C1.1, U4.P$28 (VDD), U$1.P$2 (2), U$1.P$10 (2), U$1.P$18 (2), U$2.P$2 (2), U$2.P$10 (2), U$2.P$18 (2), U$4.P$2 (2), U$4.P$10 (2), U$4.P$18 (2), U$5.P$5 (5), U$5.P$13 (5), U$6.P$5 (5), U$6.P$13 (5), U$7.P$5 (5), U$7.P$13 (5)
ADC: U$1.P$6 (6), U$1.P$14 (6), U$1.P$22 (6), U$2.P$6 (6), U$2.P$14 (6), U$2.P$22 (6), U$4.P$6 (6), U$4.P$14 (6), U$4.P$22 (6), U$5.P$1 (1), U$5.P$9 (1), U$6.P$1 (1), U$6.P$9 (1), U$7.P$1 (1), U$7.P$9 (1)
ADD0: LED1.9, LED2.9, S1.6, U4.P$23 (ROW2/A0)
ADD1: LED1.10, LED2.10, S1.5, U4.P$24 (ROW1/A1)
ADD2: LED1.12, LED2.12, S1.4, U4.P$25 (ROW0/A2)
COM: D1.A, LED1.16, U4.P$2 (COM0/AD)
COM1: LED1.11, U4.P$3 (COM1/KS0)
COM2: LED2.16, U4.P$4 (COM2/KS1)
COM3: LED2.11, U4.P$5 (COM3/KS2)
GND: C1.2, U4.P$1 (VSS), U$1.P$3 (3), U$1.P$11 (3), U$1.P$19 (3), U$2.P$3 (3), U$2.P$11 (3), U$2.P$19 (3), U$4.P$3 (3), U$4.P$11 (3), U$4.P$19 (3), U$5.P$4 (4), U$5.P$12 (4), U$6.P$4 (4), U$6.P$12 (4), U$7.P$4 (4), U$7.P$12 (4)
unnamed: R3.2, S1.3
unnamed: D1.C, R1.1, R2.1, R3.1
unnamed: R1.2, S1.1
unnamed: R2.2, S1.2
unnamed: LED1.7, LED2.7, U4.P$22 (ROW3/K1)
unnamed: LED1.1, LED2.1, U4.P$21 (ROW4/K2)
unnamed: LED1.18, LED2.18, U4.P$20 (ROW5/K3)
unnamed: LED1.13, LED2.13, U4.P$19 (ROW6/K4)
unnamed: LED1.6, LED2.6, U4.P$18 (ROW7/K5)
unnamed: LED1.17, LED2.17, U4.P$17 (ROW8/K6)
unnamed: LED1.15, LED2.15, U4.P$16 (ROW9/K7)
unnamed: LED1.14, LED2.14, U4.P$15 (ROW10/K8)
unnamed: LED1.2, LED2.2, U4.P$14 (ROW11/K9)
unnamed: LED1.4, LED2.4, U4.P$13 (ROW12/K10)
unnamed: LED1.5, LED2.5, U4.P$12 (ROW13/K11)
unnamed: LED1.8, LED2.8, U4.P$11 (ROW14/K12)
PWR: U$1.P$1 (1), U$1.P$9 (1), U$1.P$17 (1), U$2.P$1 (1), U$2.P$9 (1), U$2.P$17 (1), U$4.P$1 (1), U$4.P$9 (1), U$4.P$17 (1), U$5.P$6 (6), U$5.P$14 (6), U$6.P$6 (6), U$6.P$14 (6), U$7.P$6 (6), U$7.P$14 (6)
SCL: U4.P$26 (SCL), U$1.P$5 (5), U$1.P$13 (5), U$1.P$21 (5), U$2.P$5 (5), U$2.P$13 (5), U$2.P$21 (5), U$4.P$5 (5), U$4.P$13 (5), U$4.P$21 (5), U$5.P$2 (2), U$5.P$10 (2), U$6.P$2 (2), U$6.P$10 (2), U$7.P$2 (2), U$7.P$10 (2)
SDA: U4.P$27 (SDA), U$1.P$4 (4), U$1.P$12 (4), U$1.P$20 (4), U$2.P$4 (4), U$2.P$12 (4), U$2.P$20 (4), U$4.P$4 (4), U$4.P$12 (4), U$4.P$20 (4), U$5.P$3 (3), U$5.P$11 (3), U$6.P$3 (3), U$6.P$11 (3), U$7.P$3 (3), U$7.P$11 (3)

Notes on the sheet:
14 Segments
richardhawthorn.com
Richard Hawthorn
CLEAR BOTH SIDES OF SJ1
TO DISABLE I2C PULLUP RESISTORS
7-bit I2C Address is 0x40
I2C write is 0x80
I2C read is 0x81
VCC = 3.6V Max
Read Address:
Write Address:
Slave Address:
0x60
0xC1
0xC0



Board: 2 copper layers, 64.0 x 32.0 mm, 16 parts (8 on the bottom side), 29 nets.

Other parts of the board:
U$3: OSHW-LOGO-S

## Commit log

2018-01-28 add boards
    [RH034.2.brd, RH034.2.sch, RH035.2.brd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]
2018-01-28 add pcb images
2018-01-28 update images for button board

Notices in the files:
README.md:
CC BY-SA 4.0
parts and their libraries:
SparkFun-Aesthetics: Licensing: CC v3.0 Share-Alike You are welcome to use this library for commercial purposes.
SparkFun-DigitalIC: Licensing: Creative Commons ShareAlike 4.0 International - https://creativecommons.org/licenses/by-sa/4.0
